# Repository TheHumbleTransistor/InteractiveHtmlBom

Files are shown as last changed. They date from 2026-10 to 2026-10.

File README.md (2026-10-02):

# Interactive HTML BOM plugin for KiCad
## Supports EasyEDA, Eagle, Fusion360 and Allegro PCB designer

icon

This plugin generates a convenient Bill of Materials (BOM) listing with the
ability to visually correlate and easily search for components and their placements
on the PCB. It is particularly useful when hand-soldering a prototype, as it allows
users to quickly find locations of components groups on the board. It is also possible
to reverse lookup the component group by clicking on a footprint on the board drawing.

The plugin utilizes Pcbnew python API to read PCB data and render silkscreen, fab layer,
footprint pads, text, and drawings. BOM table fields and grouping is fully configurable,
additional columns, such as a manufacturer ID, can be added in Schematic editor and
imported either through the netlist file, XML file generated by Eeschema's internal
BOM tool, or from board file itself.

There is an option to include tracks/zones data as well as netlist information allowing
dynamic highlight of nets on the board.

For full description of functionality see [wiki](https://github.com/openscopeproject/InteractiveHtmlBom/wiki).

Generated html page is fully self contained, doesn't need internet connection to work
and can be packaged with documentation of your project or hosted anywhere on the web.

[A demo is worth a thousand words.](https://openscopeproject.org/InteractiveHtmlBomDemo/)

## 3D board view (this fork)

Adds a **3D** button beside F / FB / B. Selecting a BOM row highlights those parts in the 3D
scene and frames the camera on them. When a 3D model is embedded the BOM opens in the 3D view,
unless the browser has saved another choice.

```sh
kicad-cli pcb export glb --include-pads --include-silkscreen --include-soldermask \
    -o board.glb board.kicad_pcb
generate_interactive_bom --glb board.glb board.kicad_pcb
```

Without `--glb` nothing changes: the button is hidden and the output is byte-comparable to
upstream. The `.glb` is embedded, so the result is still one self-contained HTML file.

`--include-silkscreen` is worth the bytes -- reference designators and legends make the 3D view
navigable rather than a field of anonymous grey blocks. Measured on a 170 x 70 mm board:

| glb flags | glb | added to the html |
|---|---|---|
| none | 3.2 MB | 4.3 MB |
| `--include-silkscreen --include-soldermask` | 5.4 MB | 7.2 MB |
| ...`--include-pads` as well (recommended) | 10.6 MB | 14.2 MB |
| ...`--include-tracks` as well | 16.4 MB | 21.9 MB (not worth it) |

three.js adds a further ~2 MB. Pads double the file and are worth it: without them an unplaced
part's land pattern is invisible, which is exactly what an assembler needs to see.

### Z-fighting, and what actually caused it

The artwork layers stipple if you get this wrong. On this board they sit at 1.460 (substrate) /
1.500 (copper) / 1.535 (mask) / 1.545 mm (silk) -- **nothing is coplanar**, the closest pair is
10 um apart. The cause was depth-buffer precision, not coplanarity:

| | near | far | ratio | depth step at the board |
|---|---|---|---|---|
| before | dist/1000 | dist x 10 | 10000 | **17.9 um** -- cannot resolve a 10 um gap |
| after | dist x 0.02 | dist x 4 | 267 | **0.89 um** |

A perspective depth buffer spends most of its precision near the near plane, so an absurd
far/near ratio starves the far end. `setDepthRange()` recomputes it on every frame, because
the camera controls change the viewing distance without going through the fit code. A flat
`polygonOffset` of -1 on artwork faces remains as a cheap guard for boards where faces genuinely
do coincide -- deliberately flat rather than ranked, since large offsets make artwork bleed
through component edges at grazing angles.

### Pin 1

Honours the existing **Highlight first pin** setting (`none` / `all` / `selected`). Each pin-1 pad
gets a 3D marker: a sphere whose bottom sits on top of the part's 3D model, on a cone that runs down
to touch the pad and meets the sphere where their surfaces are tangent. So the marker clears its own
part, with the sphere held between 1.25 mm and 2.5 mm off the board; above that, the 15° outward
lean keeps it off a tall body. A through-hole pin 1 is marked on both faces of the board; on the far
side the sphere clears the leads poking through. A pin-1 marker is plain. A part with no pin 1
(2-4 pads, none named 1, e.g. a diode whose pads are K and A) gets a marker on each pad instead,
with that pad's name printed on the sphere's outer cap, and no pin-1 mark in 2D. The name is fixed
to the marker rather than turning to face the camera; it reads upright with the board's top edge up,
and on bottom-side markers from below. The marker is white at 70 % opacity, with its text opaque.

Every marker's sphere has the same radius, 0.21 mm, so the marker is sized in board millimetres and
grows and shrinks with zoom like the rest of the board. **3D: Pin 1 marker size** in the settings
menu scales it (50–200 %). Markers have their own render pass and light, so the board's dimming
doesn't reach them.

The cone's tip sits on the **board face**, not on the footprint node's origin: the origin is
skewed by any z offset the 3D model carries (`J5`'s is 3.85 mm, which left its mark hovering in
mid-air), and the land pattern is where the mark belongs anyway. It is also drawn for parts the placed
filter is hiding -- an unfitted part is exactly when you need to know which end pin 1 is.

This needs a board-millimetres to model-units mapping, which is the one place the refdes trick
does not reach. It is **solved at load time from every footprint present on both sides**, not
assumed: measured on KiCad 10 the mapping is the identity (board x,y in mm to model x,z in
metres, no offset, no sign flip), and the fit confirms it at a 0.000 mm median residual over 142
footprints. Judge such a fit on the MEDIAN residual, never the worst -- a footprint whose 3D
model carries its own `(offset ...)` is a legitimate outlier, and there were 8 of them. If the
fit fails the markers are disabled with a console warning rather than drawn in the wrong place.

### Silkscreen

The existing **Silkscreen** checkbox governs the 3D view as well as the 2D canvas — no new control;
`silkscreenVisible()` calls into the 3D module the same way `setHighlightPin1()` does.

Silkscreen is identified as the **board-level flat face beyond the mask** on either side, collected
during the pass `tintBoardLayers()` already makes. The board-level part is load-bearing, not
cosmetic: "beyond the front mask" alone means `y > 1.510 mm`, which is *every component on the
board*. Excluding `footprintMeshes` is what makes this the silkscreen rather than the whole
assembly, and the test asserts exactly that — 1154 faces toggle while the component count holds at
7608 in every state.

### The settings menu

All three 3D controls sit together at the end of the view-settings block, between *Offset back
rotation* and *Bom checkboxes*, and each label is prefixed `3D:`.

A **3D view** heading row was tried first and removed: every row in this menu is a bordered box of
the same weight, so a heading reads as just another setting rather than a section title. The prefix
does the grouping work on its own. For the same reason the first 3D row does not get
`menu-label-top` — only the very first row of the whole menu carries a top border, and adding a
divider here would be another visual device of the kind that did not work.

The **Footprint column is hidden by default** (`hiddenColumns` in `initDefaults()`). Default only:
a stored preference wins, the existing `.filter(e => fields.includes(e))` drops it harmlessly on a
BOM with no such column, and the column stays available to re-enable in the column menu.

### Zoom on select

A **3D: Zoom on select** slider in the settings menu. It works like cropping: the percentage is how
much of the board is cropped out of view, centred on the selected parts.

- **0 % (default):** the camera doesn't move; selecting a row only highlights it.
- **10 %** shows about 90 % of the board's area, **50 %** about half, and so on up to **100 %**.
- However high the setting, the camera never gets so close that the selection fills more than 20 %
  of the view, so there is always some board around it for context. It never zooms out past the
  whole board either, so deselecting returns to the whole-board view.

The zoom is absolute, worked out fresh on every selection, so selecting the same row again doesn't
zoom further. The view direction is kept; only the target and distance change. A new value applies
on the next selection.

### Free rotation

The board turns freely in every direction, over the top and underneath, with no stop at the poles:
the view uses three.js's TrackballControls rather than OrbitControls, which keeps a fixed "up"
direction. Left-drag rotates, the wheel zooms and right-drag pans, as before.

### Flip to the selection

Selecting parts that are all on the side facing away from the camera turns the board over, like
turning a page: over half a second the camera rotates half a turn about the line on the board that
looks vertical on screen, keeping its distance. The result is what you'd see after flipping the
board over by hand. If any selected part is on the visible side, the view stays put. The key light
follows the camera to whichever side it is on, so the underside is lit like the top.

### Deselecting

Upstream iBOM has no way to clear a selection: `clearHighlightedFootprints()` is only reachable by
switching BOM mode, and `createRowHighlightHandler()` returns early on the already-selected row.
Tolerable for a highlight tint on the 2D canvas; not for the 3D view, where a selection also dims the
board and holds the camera. This fork adds two ways out:

- **Escape** — works in either mode, hooked into the existing `document.onkeydown` switch.
- **Double-clicking the 3D view** — no raycast; any double-click means "get me out of this",
  whether it lands on a part or on bare board. The camera controls bind no `dblclick` of their own and a
  double-click involves no drag, so the camera is untouched.
- **Clicking the selected row again** — click mode only. In hover mode (the default, when
  *Highlight row only on click* is off) that same handler is bound to `onmousemove` and fires on every
  movement within the row, so toggling there would strobe.

Worth knowing: with the default hover mode the selection follows the mouse across the table and
never clears on its own. Turning on *Highlight row only on click* makes selection deliberate.

### 3D: Board mask

A 0–100 % slider in the settings menu, **75 % by default**. While a row is selected it darkens the board
and every unselected component, leaving the green highlighted parts bright — useful on a dense board,
and especially at 0 % auto-zoom where the camera no longer flies to the selection.

**Implemented by turning the lights down, not by recolouring materials.** The highlight is emissive,
and emissive is added independently of scene lighting, so scaling `scene.environmentIntensity` and
the key light darkens everything *except* the selection. Two lines, against cloning and restoring
~36 materials across 7608 meshes. Measured inside the 3D pane:

| slider | `environmentIntensity` | board (non-highlight) | highlight, mean R |
|---|---|---|---|
| 0 % | 0.62 | 92.3 | 174.1 |
| 50 % | 0.341 | 74.9 | 200.6 |
| 100 % | 0.062 | **34.7** | **214.5** |

`DIM_FLOOR` is the light scale at 100 %; the slider lerps between 1 and it.

The selected part's *diffuse* darkens along with everything else, so its emissive is raised while
dimming (`HIGHLIGHT_EMISSIVE_DIM`) or it reads as a muddy dark part with a red tinge rather than a
clean red one. `DIM_FACTOR` controls how far down everything else goes.

Only active while something is selected — deselecting restores the lights, verified. Pin-1 markers are
drawn in their own pass with their own lighting, so they stay bright on the dimmed board;
deliberate, they are a marker rather than scenery.

### Only show placed parts

A **3D: only show placed parts** checkbox in the settings menu, on by default. With it on, the 3D view shows
only the parts ticked in the BOM's *Placed* column -- so the board fills in as you assemble it,
and at a glance you see what the half-built board in front of you should look like.

**DNP parts are hidden in 3D until they are ticked Placed**, whether or not this is on.
Selecting one reveals it with a red highlight instead of the usual green. A DNP part that has
been ticked Placed is shown tinted red. A
part counts as DNP if `--dnp-field` marks it or KiCad's own DNP flag (`kicad_dnp`) is set.

**Land patterns stay visible, and selecting an unplaced row reveals that part** — fully opaque,
exactly as a placed part looks — so you can see the shape of the thing you are about to fit.

It was briefly revealed as a *translucent* ghost instead, which rendered as a see-through tangle of
red edges. The culprit was the `depthWrite = false` that the transparency required: it also stops
the part's own faces occluding **each other**, so every back face and interior surface showed
through the front. No opacity value fixes that — the geometry is self-overlapping and unsorted.
Opaque is both correct and less code.

Nothing is overlaid on the components themselves -- no tint, no shading, no transparency -- so a
populated board renders as it really looks and the green highlight is the only thing distinguishing
a selection. Verified by material inspection: of 7608 component meshes, 0 are transparent, 0
share a tinted material and 0 carry a polygon offset. Both matter for the actual workflow: you need to see where a part goes,
and what it looks like, *before* you can fit it and tick it off.

**Pads and silkscreen are board-level, not children of the footprint node** -- so hiding a part
is simply `node.visible = false` and the land pattern stays put. Counted on this board:

| plane (mm) | under footprints | board-level | what |
|---|---|---|---|
| 1.545 | **371** | 0 | component bottom faces |
| 1.535 | 0 | 1153 | silkscreen |
| 1.510 | 0 | 1 | top soldermask, one full-board mesh |
| 1.500 | 0 | 582 | top copper |
| 1.460 | 0 | 500 | substrate, top face |
| 0.000 | 0 | 84 | substrate, bottom face |
| −0.040 | 0 | 166 | bottom copper |
| −0.050 | 0 | 1 | bottom soldermask, one full-board mesh |

Earlier versions tried to split each footprint into "artwork" and "body" by height, on the belief
that pads were inside it. They are not, and every height rule tried caught component geometry
instead -- a +/-0.2 mm window took TSSOP leads at 1.58-1.70 mm, and "a plane shared by most
footprints" took the 1.545 mm bottom faces, which is true of every SMD's underside. Hiding a part
left a flat cross-section of it welded to the board. **Measure which meshes are actually inside
the node before designing a rule around it.**

### DNP parts

DNP parts are marked so an assembler can't miss them. Every badge below explains itself on hover,
and clicking it shows the same text, which also works on touchscreens:

- **BOM:** DNP refs are red and struck through, and a row that is entirely DNP is tinted red with lightened text and a red stripe that stays when the row is
  selected.
- **2D and 3D:** a red cross over each DNP footprint, shown while the **DNP markers** setting is
  on (the default). A selected DNP part is highlighted red in both views instead of green. In 3D
  the cross sits on the bare land pattern, and the part is tinted red once it is ticked Placed.
- **Checkbox progress** (e.g. *Placed 0/140*) leaves DNP parts out of the total.
- **Grouping** always puts DNP parts in their own row, whatever `--group-fields` says.
- **Ticking Placed** (or whichever column `--mark-when-checked` names) on a DNP row asks for
  confirmation first. The operator can still go ahead.
- Hovering a red, struck-through reference explains it ("DNP = Do Not Populate").
- KiCad's DNP column (`kicad_dnp`) is headed **DNP** and shows a red **DNP** badge on DNP rows. It
  is hidden by default (the column menu brings it back), and left out entirely on a board with no
  DNP parts in the BOM.

A part counts as DNP if `--dnp-field` marks it or KiCad's DNP flag (`kicad_dnp`) is set. A part
whose *value* says "DNP" (as a word, any case) is treated as DNP too, and its value cell gets a
yellow **WARNING** badge: DNP belongs in KiCad's DNP property, not the value.

### Lighting

**Every component material KiCad exports is `metalness: 1`** -- all 7608 meshes on this board.
A fully metallic surface has no diffuse response, so with only lights and nothing to reflect it
can only render dark: a connector housing whose material is pure white measured RGB ~120, i.e.
grey. Raising light intensities does not help, because a metal barely responds to a light at all.

The fix is image-based lighting -- `RoomEnvironment` through `PMREMGenerator`, giving those metals
a full hemisphere to reflect -- plus one soft directional light so shapes still read. A white part
now renders ~210 from any angle.

**Tone mapping is not cosmetic here.** Without it, values above 1.0 clip and a white part becomes a
flat 255 across its whole face, losing all shape. `NeutralToneMapping` (Khronos PBR Neutral) rolls
highlights off while holding colours where they are; it exists for product visualisation, which is
exactly this job. ACES works too but shifts hue. Measured on the same white part: **0.06 % of
pixels clipped**, against a blown-out face before.

`ENV_INTENSITY`, `KEY_INTENSITY` and `TONE_EXPOSURE` are at the top of `ibom3d.js`. Note that
changing them changes the *board* too -- `MASK_COLOR` and `COPPER_COLOR` were both retuned darker
once IBL raised the overall exposure.

### Layer colours

KiCad **does** honour the stackup for silkscreen -- this board declares white silk and the GLB
carries `#f5f5f5` -- but gives copper a flat `#808080`, which is nobody's idea of copper. Both
soldermask and copper are therefore tinted, and the mask is made slightly translucent so the
copper beneath reads through. A green board is what reads as "a PCB" on screen whatever the real
stackup says; set `MASK_COLOR = null` to keep the exported colour instead. `MASK_COLOR`,
`MASK_OPACITY`, `COPPER_COLOR`, `COPPER_METALNESS` and `COPPER_ROUGHNESS` are at the top of
`ibom3d.js`.

Copper also needs its **PBR properties** overridden, not just its colour. KiCad exports it as
`metalness 1 / roughness 0.4`, and a fully metallic surface has no diffuse term -- with no
environment map to reflect, it is black except where a light happens to catch it. Measured over
the copper-toned pixels of an isolated render:

| | copper pixels | mean RGB |
|---|---|---|
| metalness 1, top-down | 5367 | (140, 121, 82) |
| metalness 1, shallow | **0 -- none** | copper vanishes |
| metalness 0, top-down | 5730 | (225, 197, 138) |
| metalness 0, shallow | 4050 | (221, 192, 134) |

At `metalness 0 / roughness 0.7` the colour is within ~2 % across viewing angles.

Identify the layers by **area**, not mesh count or height rank: the full-board planes on a side are
the substrate face and the mask, and copper is the busiest plane between them. Ranking from the top
puts the tint on the silkscreen, and a "more than 20 meshes" filter discards the soldermask
outright, it being a single mesh. For the same reason `findBoardFaces()` cannot look for a
substrate *solid*: the board is flat faces too.

**Both faces are tinted**, by `identifySide()` run once per side. The rule generalises with one
substitution: the mask is the **outermost** full-board plane on its side — highest at the front,
lowest at the back — with the substrate the inner one. The back was skipped for a while
(`tintBoardLayers()` opened with `if (y < mid) return`), which left the bottom mask and copper in
KiCad's greys and reading as absent:

| plane | before | after |
|---|---|---|
| −0.050 bottom mask | `#373737` grey | `#185230` green, α 0.80 |
| −0.040 bottom copper | `#bababa` grey, **metalness 1** | `#c3903e` gold, metalness 0 |

Note the bottom copper arrived at `metalness 1`, so it had the black-at-grazing-angles problem too;
routing it through the same tint pass fixes that as well.

It rides iBOM's own `CHECKBOX_CHANGE_EVENT`, so no checkbox bookkeeping is patched. It follows
whichever column `--mark-when-checked` names, defaulting to `Placed`.

**How the mapping works.** KiCad's GLB export names every scene node for its reference
designator, so a BOM row finds its geometry by name -- no coordinate transform, no lookup table
to keep in sync, and it survives the board moving underneath it. Parts with no 3D model are
skipped and counted in a corner note. On this project's board 142 of 178 footprints have named
nodes, and the 36 that do not are exactly the `TP*`/`MH*`/`FID*`/logo set that iBOM already
excludes from the BOM -- so no BOM row is ever unmatched.

**Design notes**, mostly so they are not re-litigated:

- three.js r169 is vendored **unmodified** under `web/three/` (MIT, `LICENSE` included) and
  inlined as `data:` URIs in an import map. ES modules cannot be concatenated and three.js has
  shipped no UMD build since r160, so something must resolve the bare `three` specifier inside
  an inlined `<script type=module>`. A `data:` import map does it **with no bundler**, which
  keeps the single-file property and adds no Node toolchain.
- The one build-time edit: `GLTFLoader` imports `BufferGeometryUtils` by *relative* path, and a
  relative specifier cannot resolve when the importing module is itself a `data:` URI. That
  single import is rewritten to a bare specifier in `core/ibom.py`; the vendored file on disk
  stays pristine.
- KiCad exports GLB in **metres**, not millimetres.
- `tests/check_3d.py` screenshots a generated file in headless Chromium (software WebGL, no GPU
  needed). It is the only thing that can catch a blank 3D pane, which is otherwise silent.

### Demo board

`demo/` holds a small KiCad 10 board for trying changes without another project. R4 and C5 are DNP
through KiCad's DNP property, and R7 only through its value ("DNP"), which shows the WARNING badge.
R6 and C6 are on the back. D1's pads are named K and A rather than numbered, which shows how a part
with no pin 1 is labelled. Every part has a Manufacturer and MPN. Its 3D models are copied into
`demo/3dmodels/`, so it builds without KiCad's model library.

```sh
demo/build.sh                 # -> demo/out/ibom-demo.html
```

It needs `kicad-cli` and a python that can `import pcbnew` (`$PYTHON`, default `/usr/bin/python3`).
CI runs the same script for every pull request and for pushes to `master`, and keeps the result as
the `ibom-demo.html` artifact (unzipped) for 30 days. On a pull request, each build
posts a new comment linking its demo; a newer push cancels a build still in progress, so only the
latest commit gets one. Pushing a `v*` tag also attaches the demo to that tag's release as
`ibom-demo-<tag>.html`, creating the release if there isn't one.

### Mounting type

A **Mounting Type** column, visible by default, shows **SMT** (grey rounded rectangle, a pad) or
**TH** (grey ring, an annular ring). Sort on it to group the two, or type `smt` / `th` in the
filter box. Hovering the header or a value explains the acronym.

The value comes from KiCad's footprint type (Footprint Properties, *SMD* or *Through hole*). A
footprint left *Unspecified*, or a board from another EDA tool, counts as TH if any of its pads is
through-hole and SMT otherwise.

### Default columns

Without `--show-fields` the BOM shows **Manufacturer** and **MPN** columns alongside Value and
Footprint, even on a board where no part sets them. Grouping still defaults to Value and Footprint.

### Side, and sorting by more than one column

A **Side** column, visible by default, shows **Top** or **Bottom**. While it is shown, a group with
parts on both sides is split into a top row and a bottom row; hide the column and they merge back.

**Shift+click** a column header to add it as a further sort key, e.g. Side then Mounting Type. A
small number on each sorted header shows its priority. A plain click sorts by that column alone.

### Polarized parts and pin 1

Each part is classified **Yes**, **No** or **Unknown** for whether its orientation matters. The
classification is shown in a **Polarized** column, hidden by default (the column menu shows it).

- **No** requires evidence from the part's schematic symbol and none to the contrary: a two-pad
  R, C, L, FB or F whose Description (copied from the symbol) reads "Resistor", "Unpolarized
  capacitor", "Inductor", "Ferrite bead", "Fuse" or mentions ceramic, or whose symbol footprint
  filters are `R_*`, `C_*`, `L_*` and the like, **and** whose footprint silkscreen is symmetric
  about both of its axes (a "+", cathode band or pin-1 dot breaks that). The footprint alone never
  makes a part No, since polarized capacitors are often placed on plain, symmetric `C_` footprints.
- **Yes**: a polarity signal (`CP_` footprint or filter, "Polarized capacitor", a diode or LED), or
  more than two pins.
- **Unknown**: everything else, including conflicting evidence (a bidirectional TVS diode, an
  inductor whose footprint marks pin 1), no silkscreen, or no symbol fields at all.

**Omit pin-1 marker on bidirectional parts**, on by default, hides the pin-1 marks of parts classified No,
in both the 2D and 3D views. Turn it off to mark every part again. Yes and Unknown parts always keep
their marks.

### Sound Effect on Placed

Off by default. With it on, ticking a line's Placed box plays a clay block being set down for each
of its parts, stepping up in pitch as the stack grows, up to 10. Lines ticked during a run, or
within half a second after it, add to the same run. Placing the last part plays a short fanfare.
Unticking is silent. The sound is synthesised in the browser, so the BOM carries no audio files.

## Installation and Usage

See [project wiki](https://github.com/openscopeproject/InteractiveHtmlBom/wiki/Installation) for instructions.

## License and credits

Plugin code is licensed under MIT license, see `LICENSE` for more info.

Html page uses [Split.js](https://github.com/nathancahill/Split.js),
[PEP.js](https://github.com/jquery/PEP) and (stripped down)
[lz-string.js](https://github.com/pieroxy/lz-string) libraries that get embedded into
generated bom page.

`units.py` is borrowed from [KiBom](https://github.com/SchrodingersGat/KiBoM)
plugin (MIT license).

`svgpath.py` is heavily based on
[svgpathtools](https://github.com/mathandy/svgpathtools) module (MIT license).

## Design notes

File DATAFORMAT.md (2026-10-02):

# pcbdata struct

This document describes pcbdata json structure that plugin
extracts from PCB file and injects into generated bom page.

Notes on conventions:
* Coordinate system has origin in top left corner i.e. Y grows downwards
* All angles are in degrees measured clockwise from positive X axis vector
* Units are arbitrary but some browsers will not handle too large numbers
  well so sticking to mm/mils is preferred.

```js
pcbdata = {
   // Describes bounding box of all edge cut drawings.
   // Used for determining default zoom and pan values to fit
   // whole board on canvas.
  "edges_bbox": {
    "minx": 1,
    "miny": 2,
    "maxx": 100,
    "maxy": 200,
  },
  // Describes all edge cut drawings including ones in footprints.
  // See drawing structure description below.
  "edges": [drawing1, drawing2, ...],
  "drawings": {
    // Contains all drawings + reference + value texts on silkscreen
    // layer grouped by front and back.
    "silkscreen": {
      "F": [drawing1, drawing2, ...],
      "B": [drawing1, drawing2, ...],
    },
    // Same as above but for fabrication layer.
    "fabrication": {
      "F": [drawing1, drawing2, ...],
      "B": [drawing1, drawing2, ...],
    },
  },
  // Describes footprints.
  // See footprint structure description below.
  // index of entry corresponds to component's numeric ID
  "footprints": [
    footprint1,
    footprint2,
    ...
  ],
  // Optional track data. Vias are 0 length tracks.
  "tracks": {
    "F": [
      {
        // In case of line segment or via (via is 0 length segment)
        "start": [x, y],
        "end": [x, y],
        // In case of arc
        "center": [x, y],
        "startangle":
        "radius": radius,
        "startangle": angle1,
        "endangle": angle2,
        // Common fields
        "width": w,
        // Optional net name
        "net": netname,
        // Optional drill diameter (un-tented vias only)
        "drillsize": x
      },
      ...
    ],
    "B": [...]
  },
  // Optional zone data (should be present if tracks are present).
  "zones": {
    "F": [
      {
        // SVG path of the polygon given as 'd' attribute of svg spec.
        // If "svgpath" is present "polygons" is ignored.
        "svgpath": svgpath,
        // optional fillrule flag, defaults to nonzero
        "fillrule": "nonzero" | "evenodd",
        "polygons": [
          // Set of polylines same as in polygon drawing.
          [[point1x, point1y], [point2x, point2y], ...],
        ],
        // Optional net name.
        "net": netname,
      },
      ...
    ],
    "B": [...]
  },
  // Optional net name list.
  "nets": [net1, net2, ...],
  // PCB metadata from the title block.
  "metadata": {
    "title": "title",
    "revision": "rev",
    "company": "Horns and Hoofs",
    "date": "2019-04-18",
    "variant": "var" // optional
  },
  // Contains full bom table as well as filtered by front/back.
  // See bom row description below.
  "bom": {
    "both": [bomrow1, bomrow2, ...],
    "F":  [bomrow1, bomrow2, ...],
    "B":  [bomrow1, bomrow2, ...],
    // numeric IDs of DNP components that are not in BOM
    "skipped": [id1, id2, ...],
    // numeric IDs of all DNP components, whether or not they are in BOM
    "dnp": [id1, id2, ...],
    // numeric IDs of components that are DNP only because their value says
    // "DNP" (a subset of "dnp")
    "dnp_value": [id1, id2, ...],
    // Fields map is keyed on component ID with values being field data.
    // It's order corresponds to order of fields data in config struct.
    "fields" {
      id1: [field1, field2, ...],
      id2: [field1, field2, ...],
      ...
    }
  },
  // Contains parsed stroke data from newstroke font for
  // characters used on the pcb.
  "font_data": {
    "a": {
      "w": character_width,
      // Contains array of polylines that form the character shape.
      "l": [
        [[point1x, point1y], [point2x, point2y],...],
        ...
      ]
    },
    "%": {
      ...
    },
    ...
  },
}
```

# drawing struct

All drawings are either graphical items (arcs, lines, circles, curves)
or text.

Rendering method and properties are determined based on `type`
attribute.

## graphical items

### segment

```js
{
  "type": "segment",
  "start": [x, y],
  "end": [x, y],
  "width": width,
}
```

### rect

```js
{
  "type": "rect",
  "start": [x, y], // coordinates of opposing corners
  "end": [x, y],
  "width": width,
}
```

### circle

```js
{
  "type": "circle",
  "start": [x, y],
  "radius": radius,
  // Optional boolean, defaults to 0
  "filled": 0,
  // Line width (only has effect for non-filled shapes)
  "width": width,
}
```

### arc

```js
{
  "type": "arc",
  "width": width,
  // SVG path of the arc given as 'd' attribute of svg spec.
  // If this parameter is specified everything below it is ignored.
  "svgpath": svgpath,
  "start": [x, y], // arc center
  "radius": radius,
  "startangle": angle1,
  "endangle": angle2,
}
```

### curve

```js
{
  "type": "curve", // Bezier curve
  "start": [x, y],
  "end": [x, y],
  "cpa": [x, y], // control point A
  "cpb": [x, y], // control point B
  "width": width,
}
```

### polygon

```js
{
  "type": "polygon",
  // Optional, defaults to 1
  "filled": 1,
  // Line width (only has effect for non-filled shapes)
  "width": width
  // SVG path of the polygon given as 'd' attribute of svg spec.
  // If this parameter is specified everything below it is ignored.
  "svgpath": svgpath,
  "pos": [x, y],
  "angle": angle,
  "polygons": [
    // Polygons are described as set of outlines.
    [
      [point1x, point1y], [point2x, point2y], ...
    ],
    ...
  ]
}
```

## text

```js
{
  "pos": [x, y],
  "text": text,
  // SVG path of the text given as 'd' attribute of svg spec.
  // If this parameter is specified then height, width, angle,
  // text attributes and justification is ignored. Rendering engine
  // will not attempt to read character data from newstroke font and
  // will draw the path as is. "thickness" will be used as stroke width.
  "svgpath": svgpath,
  // If polygons are specified then remaining attributes are ignored
  "polygons": [
    // Polygons are described as set of outlines.
    [
      [point1x, point1y], [point2x, point2y], ...
    ],
    ...
  ],
  "height": height,
  "width": width,
  // -1: justify left/top
  // 0: justify center
  // 1: justify right/bot
  "justify": [horizontal, vertical],
  // Either the thickness or the fillrule must be used
  "thickness": thickness,
  // fillrule is only supported for svgpath
  "fillrule": "nonzero" | "evenodd",
  "attr": [
    // may include none, one or both
    "italic", "mirrored"
  ],
  "angle": angle,
  // Present only if text is reference designator
  "ref": 1,
  // Present only if text is component value
  "val": 1,
}
```

# footprint struct

Footprints are a collection of pads, drawings and some metadata.

```js
{
  "ref": reference,
  // Optional. "yes", "no" or "unknown": whether the part's orientation
  // matters. "no" only with evidence from the schematic symbol (KiCad).
  "polarized": polarized,
  // Optional. "smd" or "th" from the ECAD footprint type; if absent, the
  // footprint counts as "th" when any of its pads is through-hole.
  "mount": mount,
  "center": [x, y],
  "bbox": {
    // Position of the rotation center of the bounding box.
    "pos": [x, y],
    // Rotation angle in degrees.
    "angle": angle,
    // Left top corner position relative to center (after rotation)
    "relpos": [x, y],
    "size": [x, y],
  },
  "pads": [
    {
      "layers": [
        // Contains one or both
        "F", "B",
      ],
      "pos": [x, y],
      "size": [x, y],
      "angle": angle,
      // Only present if pad is considered first pin.
      // Pins are considered first if it's name is one of
      // 1, A, A1, P1, PAD1
      // OR footprint has no pads named as one of above and
      // current pad's name is lexicographically smallest.
      "pin1": 1,
      // Only present when the footprint has no first pin as above and 2-4
      // named pads (e.g. a diode's K and A); then every pad carries its
      // name and none is marked "pin1".
      "name": name,
      // Shape is one of "rect", "oval", "circle", "roundrect", "chamfrect", custom".
      "shape": shape,
      // Only present if shape is "custom".
      // SVG path of the polygon given as 'd' attribute of svg spec.
      // If "svgpath" is present "polygons", "pos", "angle" are ignored.
      "svgpath": svgpath,
      "polygons": [
        // Set of polylines same as in polygon drawing.
        [[point1x, point1y], [point2x, point2y], ...],
        ...
      ],
      // Only present if shape is "roundrect" or "chamfrect".
      "radius": radius,
      // Only present if shape is "chamfrect".
      // chamfpos is a bitmask, left = 1, right = 2, bottom left = 4, bottom right = 8
      "chamfpos": chamfpos,
      "chamfratio": ratio,
      // Pad type is "th" for standard and NPTH pads
      // "smd" otherwise.
      "type": type,
      // Present only if type is "th".
      // One of "circle", "oblong" or "rect".
      "drillshape": drillshape,
      // Present only if type is "th". In case of circle shape x is diameter, y is ignored.
      "drillsize": [x, y],
      // Optional attribute.
      "offset": [x, y],
      // Optional net name
      "net": netname,
    },
    ...
  ],
  "drawings": [
    // Contains only copper F_Cu, B_Cu drawings of the footprint.
    {
      // One of "F", "B".
      "layer": layer,
      // See drawing struct description above.
      "drawing": drawing,
    },
    ...
  ],
  // One of "F", "B".
  "layer": layer,
}
```

# bom row struct

Bom row is a list of reference sets

Reference set is array of tuples of (ref, id) where id is just
a unique numeric identifier for each footprint that helps avoid
collisions when references are duplicated.

```js
[
  [reference_name, footprint_id],
  ...
]
```

# config struct

```js
config = {
  "dark_mode": bool,
  "show_pads": bool,
  "show_fabrication": bool,
  "show_silkscreen": bool,
  "highlight_pin1": "none" | "all" | "selected",
  "redraw_on_drag": bool,
  "board_rotation": int,
  "checkboxes": "checkbox1,checkbox2,...",
  "bom_view": "bom-only" | "left-right" | "top-bottom",
  "layer_view": "F" | "FB" | "B",
  "extra_fields": ["field1_name", "field2_name", ...],
}
```

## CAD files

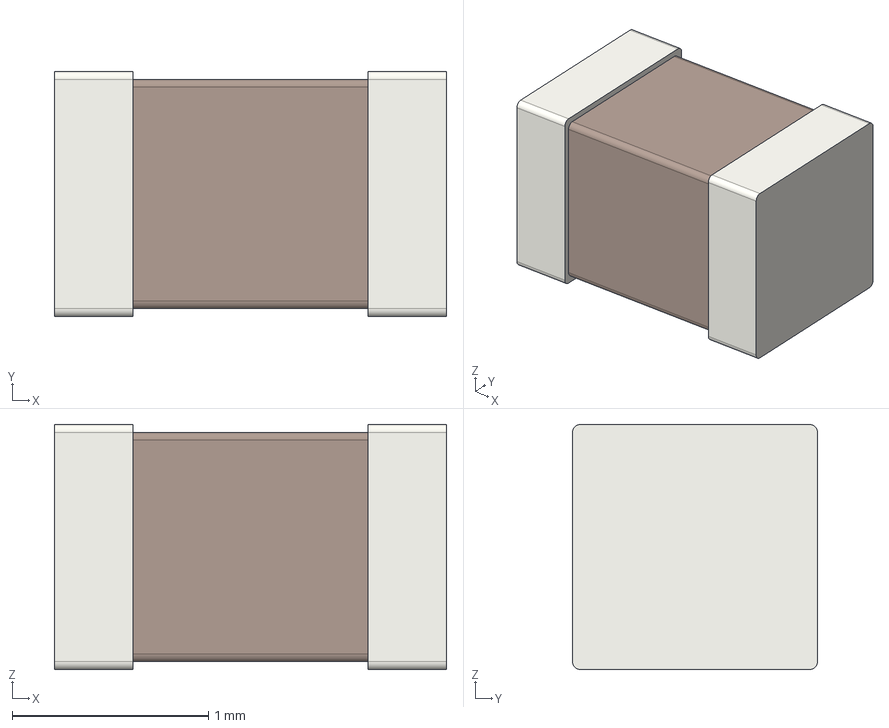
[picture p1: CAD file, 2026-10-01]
demo/3dmodels/C_0805_2012Metric.step
2.00 x 1.25 x 1.25 mm

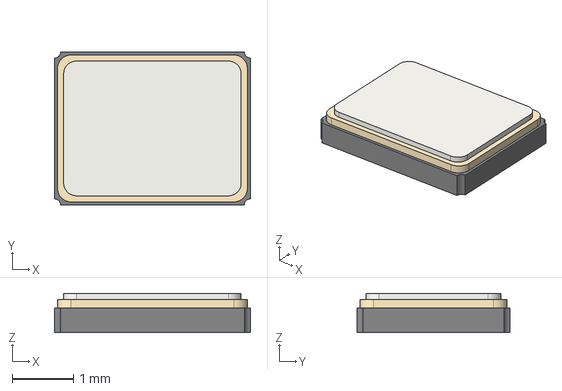
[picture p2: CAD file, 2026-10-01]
demo/3dmodels/Crystal_SMD_3225-4Pin_3.2x2.5mm.step
3.20 x 2.50 x 0.64 mm

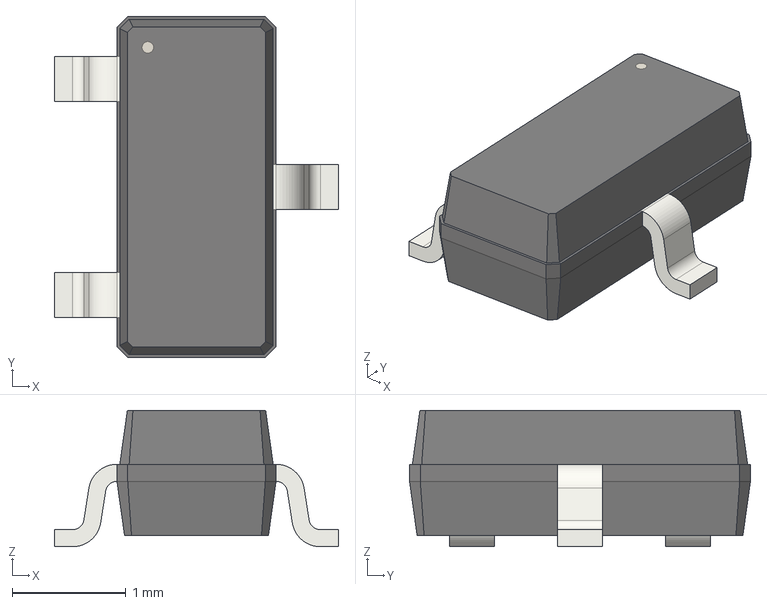
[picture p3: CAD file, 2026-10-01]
demo/3dmodels/SOT-23.step
2.50 x 3.00 x 1.20 mm

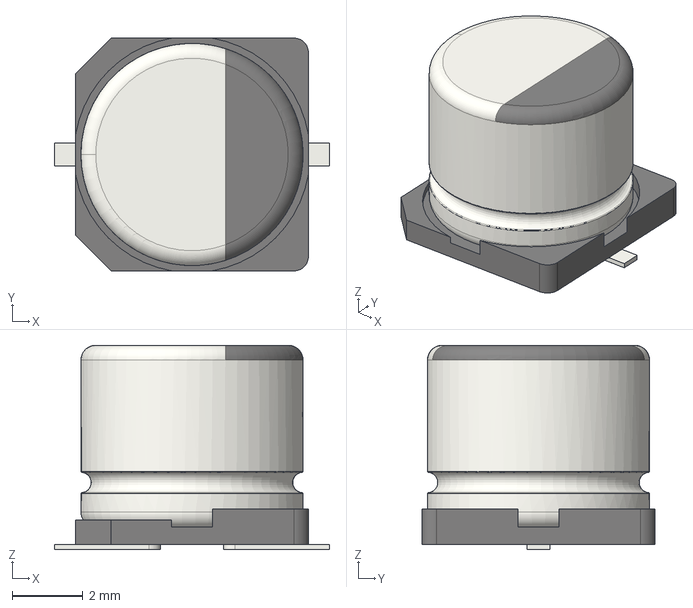
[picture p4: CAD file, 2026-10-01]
demo/3dmodels/CP_Elec_6.3x5.8.step
7.80 x 6.60 x 5.80 mm

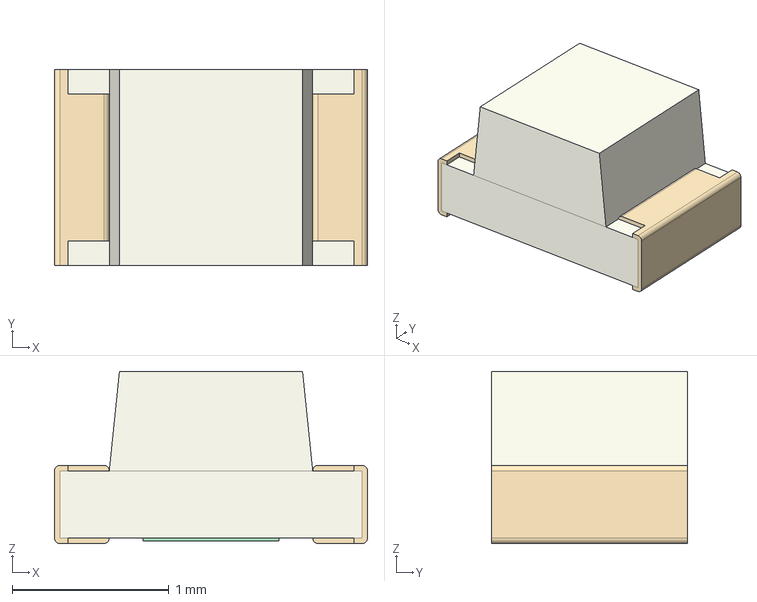
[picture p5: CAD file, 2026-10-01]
demo/3dmodels/LED_0805_2012Metric.step
2.00 x 1.25 x 1.10 mm

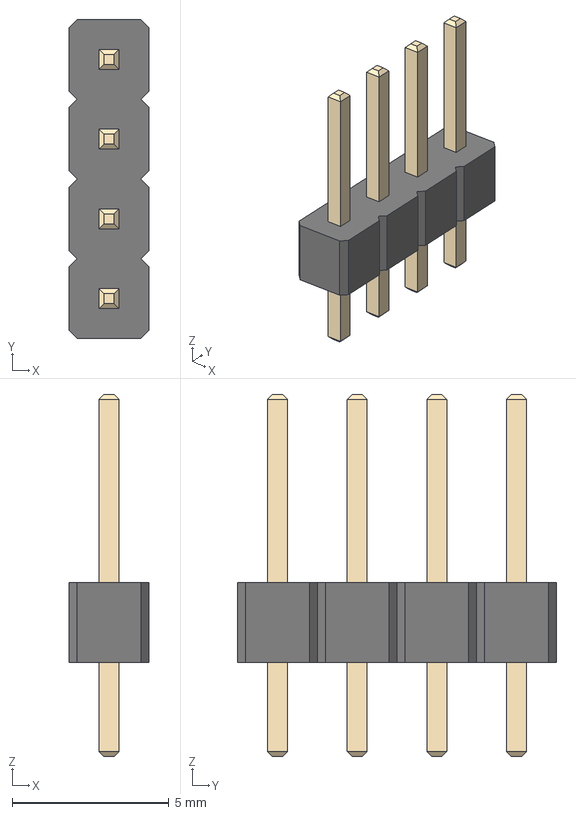
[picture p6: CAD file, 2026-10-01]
demo/3dmodels/PinHeader_1x04_P2.54mm_Vertical.step
2.54 x 10.2 x 11.5 mm

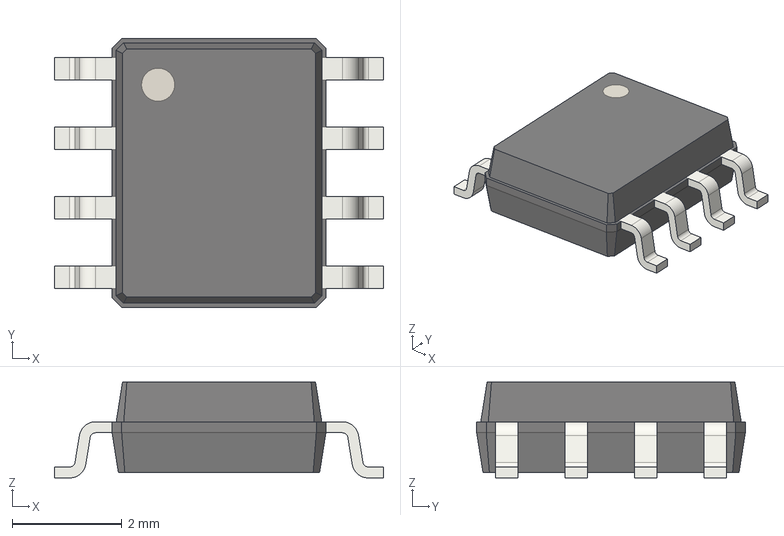
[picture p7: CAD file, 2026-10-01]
demo/3dmodels/SOIC-8_3.9x4.9mm_P1.27mm.step
6.00 x 4.90 x 1.75 mm

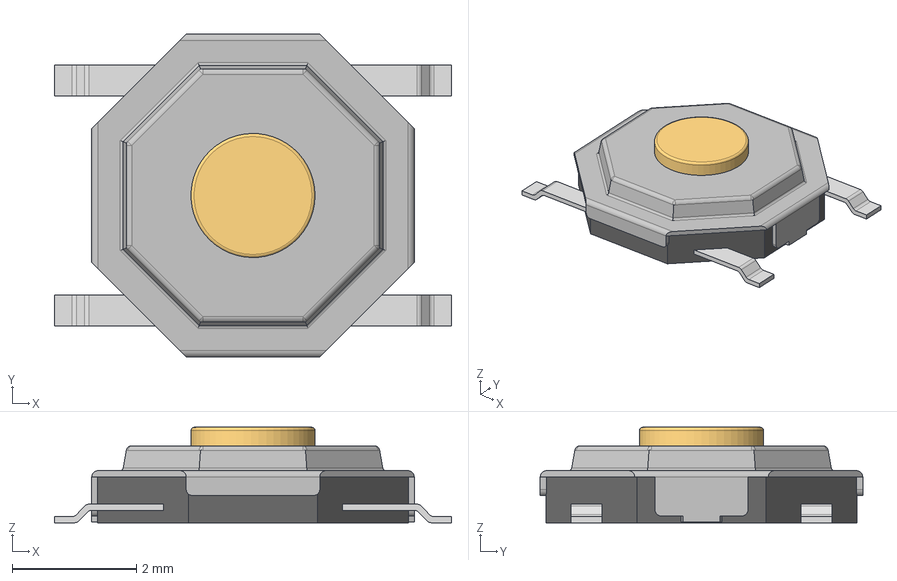
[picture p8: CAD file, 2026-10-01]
demo/3dmodels/SW_SPST_TL3342.step
6.40 x 5.20 x 1.54 mm

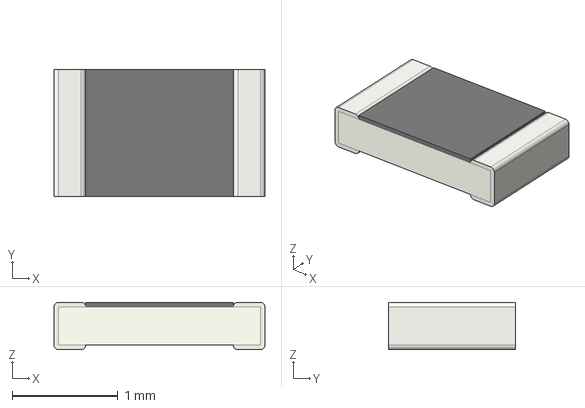
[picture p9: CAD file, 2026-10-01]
demo/3dmodels/R_0805_2012Metric.step
2.00 x 1.20 x 0.45 mm

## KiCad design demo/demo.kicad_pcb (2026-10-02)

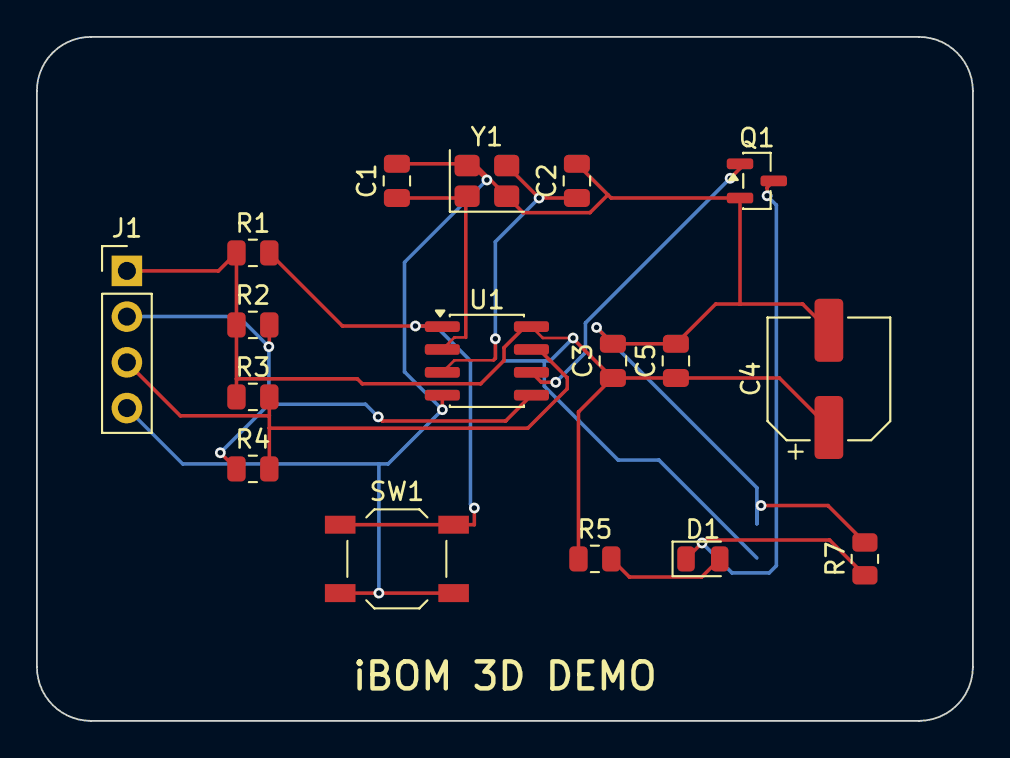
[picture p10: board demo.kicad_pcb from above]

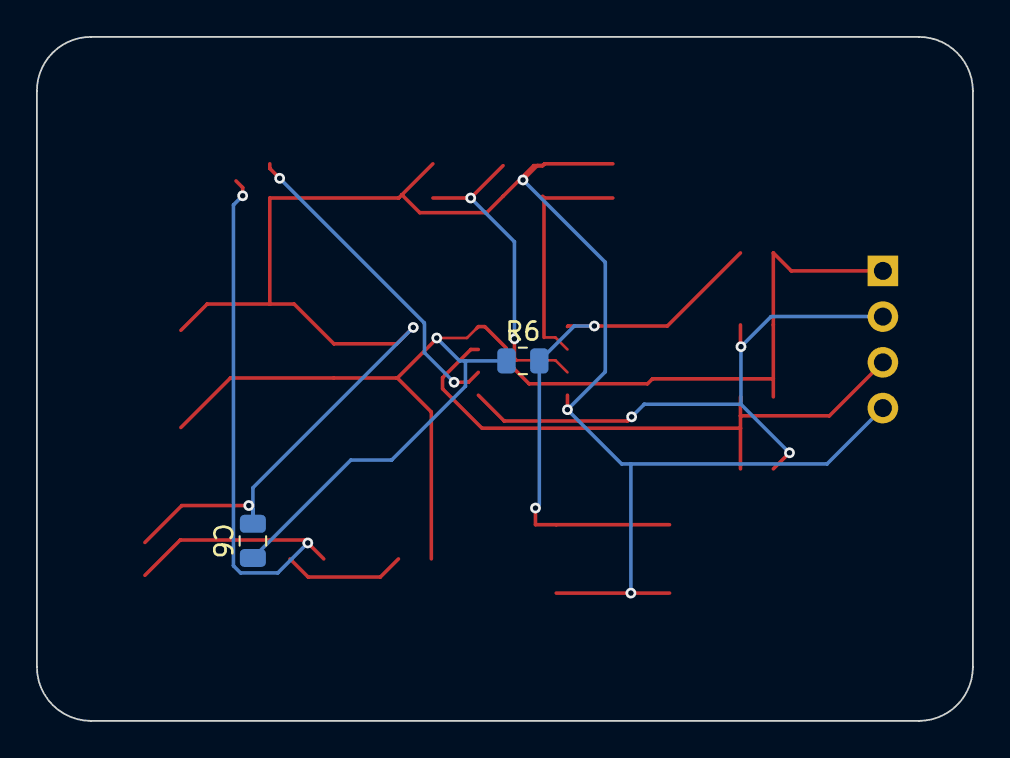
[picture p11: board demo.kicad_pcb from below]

Board: 2 copper layers, 52.0 x 38.0 mm, 19 parts (2 on the bottom side), 10 nets.

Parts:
C1, C2: 22pF; C_0805_2012Metric
C3, C6: 100nF; C_0805_2012Metric
C4: 47uF; CP_Elec_6.3x5.8
C5: 1uF; C_0805_2012Metric
D1: Green; LED_0805_2012Metric
J1: Conn_01x04; PinHeader_1x04_P2.54mm_Vertical
Q1: BSS138; SOT-23
R1, R6: 10k; R_0805_2012Metric
R2, R3: 4.7k; R_0805_2012Metric
R4: 0R; R_0805_2012Metric
R5: 1k; R_0805_2012Metric
R7: DNP; R_0805_2012Metric
SW1: Reset; SW_SPST_TL3342
U1: ATtiny85; SOIC-8_3.9x4.9mm_P1.27mm
Y1: 16MHz; Crystal_SMD_3225-4Pin_3.2x2.5mm

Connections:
GND: C1.2, C2.2, C3.2, C4.2, C5.2, C6.2, J1.4, Q1.2, R7.2, SW1.2, U1.4, Y1.2, Y1.4
LED: Q1.1, U1.6
LED_A: D1.A, R5.2
LED_K: D1.K, Q1.3, R7.1
RST: R1.2, R6.2, SW1.1, U1.1
SCL: J1.3, R3.2, R4.2, U1.7
SDA: J1.2, R2.2, R4.1, U1.5
VCC: C3.1, C4.1, C5.1, C6.1, J1.1, R1.1, R2.1, R3.1, R5.1, R6.1, U1.8
XTAL1: C1.1, U1.2, Y1.1
XTAL2: C2.1, U1.3, Y1.3

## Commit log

2026-08-21 3D board view, driven by KiCad's GLB export
    Adds a 3D button beside F / FB / B. Selecting a BOM row highlights those
    parts in the 3D scene and frames the camera on them.
    kicad-cli pcb export glb -o board.glb board.kicad_pcb
    generate_interactive_bom --glb board.glb board.kicad_pcb
    Without --glb nothing changes: the button is hidden and output matches
    upstream. Verified against a real 178-footprint board.
    WHY THIS IS NOW CHEAP. Issue #225 (2021) stalled on vrm360/VRML, which was
    reported unusable beyond small boards, and the only implementation was a
    prerendered background image. KiCad has since gained native GLB export, and
    its nodes are NAMED FOR THEIR REFERENCE DESIGNATOR -- so a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
2026-08-21 3D view: pads, real z-fighting fix, and ghosting for unplaced parts
    PADS. `--include-pads` is now part of the recommended export. Doubles the glb
    (5.4 -> 10.6 MB) and is worth it: without pads an unplaced part's land pattern
    is invisible, which is precisely what an assembler needs to see.
    Z-FIGHTING -- and the cause was NOT coplanarity. Measured, the layers sit at
    1.460 (substrate) / 1.500 (copper) / 1.535 (mask) / 1.545 mm (silk). Nothing is
    coplanar; the closest pair is 10 um apart. The problem was depth-buffer
    precision:
    before near=dist/1000 far=dist*10 ratio 10000 -> 17.9 um per step
    after near=dist*0.02 far=dist*4 ratio 267 -> 0.89 um per step
    A perspective de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
2026-08-21 3D view: fix flattened component remnants, and tint the board layers
    Two regressions from the previous commit, both reported from the bench.
    FLATTENED COMPONENTS. Hiding an unplaced part left flat fragments of it on the
    board. The artwork/body split used "flat face within 0.2 mm of a board face",
    and a TSSOP's gull-wing leads sit at 1.58-1.70 mm -- inside that window. So the
    leads were classed as artwork, exempted from hiding, and every part left a
    flattened ghost behind.
    Two further rules were tried and measured before one worked:
    - "a plane shared by >=25% of footprints is a board layer" caught 1.995 mm,
    which is simply the top face of ~60 identical 0805s;
    - "the median footprin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
2026-08-21 3D view: hide the whole footprint node; keep the mask's real colour
    FLATTENED COMPONENTS, take two. Hiding an unplaced part still left a flat
    cross-section of it on the board -- correctly diagnosed from the bench as "the
    cross section of where it meets the board". Measured, it was 371 meshes at
    1.545 mm across 139 footprints: component BOTTOM FACES.
    The root error was an assumption I never checked. Pads are NOT children of the
    footprint node:
    plane (mm) under footprints board-level what
    1.545 371 0 component bottom faces
    1.535 0 1153 silkscreen
    1.510 0 1 soldermask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
2026-08-21 3D view: raise the ghost opacity; confirm components carry no overlay
    GHOST more opaque, as asked: GHOST_OPACITY 0.32 -> 0.6 and GHOST_EMISSIVE
    0.22 -> 0.45. Clearly red now while still reading as "not yet fitted" -- the
    board and its pads remain visible through it. The two values are next to each
    other at the top of the module; the previous pass had over-corrected after the
    ghost was mistaken for a rendering fault.
    NO MASK COLOUR OR SHADING ON COMPONENTS, checked rather than asserted. Tinting
    only ever touches the two board planes the area analysis identifies, so parts
    render exactly as KiCad exported them. Measured across 7608 component meshes:
    transparent 0
    sh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
2026-08-21 3D view: pin-1 dots follow the 2D palette, and sit on the board
    COLOUR now comes from the 2D view's own `--pin1-outline-color` CSS variable
    (#ffb629 light / #ffa800 dark) rather than a hardcoded blue, so the dot matches
    the canvas and tracks dark mode for free -- render.js reads the same property.
    setDarkMode() refreshes the dots, since the variable changes under them.
    Two bugs surfaced while verifying it, both of which made the dots useless in the
    case they matter most:
    - They were positioned at the footprint NODE ORIGIN plus the dot radius. That
    origin is skewed by any z offset the 3D model carries, so J5 -- whose model
    sits 3.85 mm up -- had its dot hovering at 5.95 mm in mid-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
2026-08-21 3D view: image-based lighting, so white components render white
    Bench report: "populated component models are masked/shaded -- white components
    are appearing as grey."
    Nothing is overlaid on the components; that was checked, not assumed (0 of 7608
    meshes transparent, tinted or offset). The cause is that KiCad exports EVERY
    component material with metalness 1 -- all 7608 of them. A fully metallic
    surface has no diffuse term, so with only lights and no environment to reflect
    it can only render dark. J5's housing, whose material is literally 1,1,1 white,
    measured RGB ~120.
    That also rules out the obvious fix: raising light intensities would have done
    almost nothing, because a metal barely res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
2026-08-21 3D view: slider for how much to auto-zoom when a BOM row is selected
    Selecting a row always jumped the camera to a fit-on-the-selection, which is
    right for inspecting a part and wrong when working across the board. Now a
    0-100% slider in the settings menu, styled like Board rotation.
    0% (the default) the camera does not move at all; the row is only highlighted
    100% the previous behaviour, bit-for-bit
    The fraction is RELATIVE to where the camera already is:
    target = lerp(currentTarget, selectionCentre, pct/100)
    dist = lerp(currentDist, todaysFitDist, pct/100)
    which is what lets 0% mean "do not move" rather than "frame the whole board".
    The accepted trade, r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
2026-08-21 3D view: setting to dim the board while a row is selected
    Darkens the board and every unselected component while a BOM row is selected,
    leaving the red highlighted parts bright. Off by default. Useful on a dense
    board, and especially at the new 0% auto-zoom default where the camera no longer
    flies to the selection.
    IMPLEMENTED BY TURNING THE LIGHTS DOWN, not by recolouring materials. The
    highlight is emissive and emissive is added independently of scene lighting, so
    scaling scene.environmentIntensity and the key light darkens everything EXCEPT
    the selection. Two lines, against cloning and restoring ~36 materials across
    7608 meshes. Measured inside the 3D pane, selecting the U5/U6/U7/U9 row: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
2026-08-22 Add a way to deselect; rename the dim slider to "3D: Board mask"
    DESELECT. Reported from the bench: "How do you deselect? I'm unable to do
    that." Correct -- upstream iBOM has no way to clear a selection at all.
    clearHighlightedFootprints() is only reachable by switching BOM mode, and
    createRowHighlightHandler() returns early on the already-selected row. That is
    tolerable when a selection is just a red tint on the 2D canvas, and not once it
    also dims the board and holds the camera.
    Two additive ways out, neither of which changes existing behaviour:
    - Escape, hooked into the existing document.onkeydown switch rather than a
    competing listener. Works in both modes; ignored while a text f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
2026-08-22 Deselect on double-click in the 3D view; board mask defaults to 75%
    DOUBLE-CLICK the 3D view to clear the selection, joining Escape and
    click-the-selected-row-again. Six lines and no raycast: any double-click means
    "get me out of this", whether it lands on a part or on bare board.
    OrbitControls binds no dblclick of its own and a double-click involves no drag,
    so nothing conflicts -- verified the camera position and target are byte-equal
    across the gesture.
    Measured with the mask at 80%: selecting takes refs to 4 and
    environmentIntensity 0.62 -> 0.1736; a double-click on the canvas returns them
    to 0 and 0.62.
    BOARD MASK now defaults to 75% rather than 0. On a fresh profile that reads
    env 0.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
2026-08-22 3D view: a selected part is always opaque
    Reported from the bench: a selected but unplaced part looked buggy -- "nearly
    see-through with some red edges of the model" -- and looked fine once marked
    placed.
    The cause was the `depthWrite = false` that the ghost's transparency required.
    It does not only let the board show through the part; it stops the part's own
    faces occluding EACH OTHER, so every back face and interior surface rendered
    through the front. That is a tangle of red edges, not a translucent solid, and
    no opacity value fixes it -- the geometry is self-overlapping and unsorted.
    So a selected part is now opaque whether placed or not. The reveal branch keeps
    only the one thing it st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
2026-08-22 Settings menu: drop the "3D view" heading, prefix the labels instead
    The heading added in 7894f72 did not read as a group. Every row in this menu is
    a bordered box of the same weight, so a heading row looks like just another
    setting rather than a section title.
    Reverted to the simpler thing: the three controls stay adjacent, between Offset
    back rotation and Bom checkboxes, and each label carries a "3D:" prefix that
    does the grouping work on its own.
    Zoom on select -> 3D: Zoom on select
    Board mask -> 3D: Board mask
    Only show placed parts -> 3D: Only show placed parts
    The first 3D row deliberately does NOT get menu-label-top. Only the very first
    row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
2026-10-01 3D view: never show DNP parts
    With "3D: Only show placed parts" off, every footprint was shown, DNP
    included. DNP parts are now hidden regardless of that setting, and
    selecting one does not reveal it; the note under the view says how many
    selected parts are DNP instead.
    DNP can't be read off bom.skipped: that only holds DNP parts when
    --dnp-field is set, and it also holds blacklisted and virtual parts. A
    common setup (KiCad's DNP flag, shown as a kicad_dnp column) leaves DNP
    parts in the BOM, so pcbdata.bom gains a "dnp" list covering both
    --dnp-field and kicad_dnp.
    Verified on the pump controller board: R41/R51 (kicad_dnp) hidden with
    the filter off and on; 140 other parts visible with it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
2026-10-01 Default "Highlight first pin" to "selected"
    Changes the generation-time default (CLI, settings dialog, ini) and the
    page's fallback from "none" to "selected". A bare --highlight-pin1 still
    means "all", and an explicit value still wins.
    Fixes #3
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2026-10-01 Make DNP parts unmistakable in the BOM, 2D and 3D views
    With KiCad's DNP flag, a DNP part was an ordinary BOM row whose only
    marker was "DNP" in a text column, and it looked like any other part
    on both boards.
    - BOM: DNP refs red and struck through, a red DNP badge in the
    References cell, and all-DNP rows tinted red with a red left stripe
    that survives row selection.
    - 2D canvas: red cross over each DNP footprint's bounding box, drawn
    always; "DNP outlined" now covers kicad_dnp parts too.
    - 3D: red cross on the bare land pattern of each (hidden) DNP part.
    - Checkbox progress excludes DNP parts from the total and the count.
    Fixes #1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
2026-10-01 DNP: own BOM group, confirm before marking placed, plainer labels
    From review on #1:
    - DNP parts always get their own BOM row, whether or not --group-fields
    includes the DNP field, so a DNP part can't hide in a populated group.
    - Ticking the placed checkbox (--mark-when-checked, default "Placed") on
    a DNP row asks for confirmation first. Cancelling leaves it unticked;
    the operator can still go ahead.
    - kicad_dnp is headed "Do Not Populate" in the BOM and column menu, and
    its value is "Do Not Populate" instead of "DNP".
    - All-DNP rows also get lightened text.
    Also fixes CSV/TSV export, which only read text from MARK/A elements and
    would have written "null" for the new DNP ref spans;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
2026-10-01 Add a "DNP markers" setting for the red DNP crosses
    The red cross over DNP footprints in 2D and 3D was always on. A new
    "DNP markers" checkbox (default on, persisted like the others) now
    controls it in both views. Upstream's "DNP outlined" is unchanged; the
    BOM-side DNP styling and the red tint on a placed DNP part stay on.
    Fixes #12
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2026-10-01 BOM: add a Mounting Type column (SMT / TH)
    Assembly runs as an SMT pass followed by a through-hole pass, so a
    Mounting Type column, visible by default and sortable, shows SMT or TH
    for each row, with tooltips on the header and values. The filter box
    matches it too.
    The KiCad parser records the footprint type attribute (SMD / Through
    hole) as footprint "mount". When it is absent (footprint type left
    Unspecified, or another EDA tool), a footprint counts as TH if any pad
    is through-hole.
    Fixes #17
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2026-10-01 Mounting Type: SMT icon is a wider rectangle with tighter corners
    9 x 6.5 instead of 8 x 8, corner radius 1.8 -> 1.0.
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2026-10-01 BOM: leave out the DNP column when no BOM row is DNP
    On a board with no DNP parts in the BOM the DNP column is always empty,
    so it is dropped from the available columns: no header, no cells, no
    column-menu entry. DNP parts excluded from the BOM by --dnp-field don't
    count, since they have no row to badge.
    Fixes #18
2026-10-01 Demo board: DRC-clean placement, autorouted, rounded corners
    The first board failed DRC: a courtyard overlap, two shorts, two
    solder-mask bridges and seven silkscreen violations. Parts are now
    spread out and the outline has 3 mm corner radii.
    Routed with Freerouting 2.4.1 (all 39 connections, 128 segments, 16
    vias). It necks a few segments down to 0.15 mm between pads, so the
    board's minimum track width is 0.15 mm. kicad-cli pcb drc
    --severity-all now reports 0 violations and 0 unconnected items.
    build.sh also exports tracks into the GLB, so the routing shows in 3D.
    [demo.kicad_pcb]
2026-10-01 Treat parts whose value says "DNP" as DNP, with a WARNING badge
    A value naming the part DNP ("DNP" as a whole word, any case:
    "DNP", "dnp", "10k DNP", "DNP_10k") now marks the part DNP: its own BOM
    row, the DNP badge, red markers, hidden in 3D and the Placed
    confirmation. Its value cell also gets a yellow WARNING badge whose
    tooltip says DNP belongs in KiCad's DNP property, not the value.
    pcbdata.bom gains "dnp_value" for the badge. The DNP column now badges
    any part in the DNP list rather than reading kicad_dnp's text, so it
    covers these parts too. CSV/TSV export leaves the WARNING text out of
    the value.
    Fixes #20
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2026-10-01 3D view: keep the DNP crosses red when zoomed out
    The board artwork, soldermask included, is drawn with a -1 polygon
    offset (biasArtwork). From a distance that bias exceeded the 0.05 mm
    lift of the DNP crosses, so the translucent dark-green mask was drawn
    over them and they read as black until you zoomed in. The crosses now
    carry a -4 offset so they always win against the mask beneath them.
    Measured on the demo board, sampling the centre of each on-screen cross
    bar: at 300 mm 0/36 red pixels before, 32/36 after (bars are ~1 px
    wide there); at 150 mm 0/36 before, 36/36 after; unchanged when close.
    Fixes #34
2026-10-01 BOM: tooltip on DNP references; hide the DNP column by default
    Hovering a red, struck-through DNP reference now shows the same
    "DNP = Do Not Populate" explanation as the DNP badge, so the styling
    explains itself without the DNP column. That column joins Footprint in
    the default hidden columns; a stored choice still wins and the column
    menu brings it back.
    Fixes #39
2026-10-01 Demo board: Manufacturer/MPN on every part; R7 is DNP only by value
    Every part now carries real Manufacturer and MPN fields (hidden, on the
    Fab layer, so nothing lands on the silkscreen).
    R7 ("10k DNP", 0805, LED_K to GND) is DNP only through its value, so the
    demo shows the WARNING badge from #29 next to the two parts that use
    KiCad's DNP property (R4, C5).
    R7 routed with Freerouting; kicad-cli pcb drc --severity-all reports 0
    violations and 0 unconnected items.
    Fixes #28
    [demo.kicad_pcb]
2026-10-01 BOM: Side column, split groups by side, and multi-column sort
    A Side column (Top / Bottom), visible by default. While it is shown, a
    group with parts on both sides is split into a top row and a bottom
    row, client-side, so hiding the column merges them back without
    regenerating the BOM. The filter box matches it too.
    Shift+click on a column header adds it as a further sort key (a plain
    click still sorts by that column alone), so the BOM can be sorted by
    Side and Mounting Type together. Each sorted header shows its priority.
    Sort state is now kept by column name, so the marks survive the header
    being rebuilt.
    Fixes #36
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2026-10-01 Remove upstream's PyPI release workflow
    This fork isn't published to PyPI, and on every v* tag the workflow
    would try to publish upstream's InteractiveHtmlBom package and fail.
    Releases are handled by the Demo workflow, which attaches the demo
    iBOM to the tag's release.
2026-10-01 Version 3.0.0: the fork's own version line
    The fork no longer tracks upstream releases, so it gets its own
    version. 3.0.0 sits above upstream's 2.x on purpose: the package keeps
    upstream's name, and a lower number would let `pip install --upgrade
    InteractiveHtmlBom` replace the fork with upstream from PyPI. Unlike
    the old v2.11.2-3d.N tags, it's a valid package version, so the wheel
    and the HTML footer now report it.
2026-10-01 3D view: flip to the other side when the selection is out of view
    Selecting parts that are all on the side facing away from the camera
    now mirrors the camera through the board's plane, so the view shows
    that side at the same distance and heading. Nothing else about the
    user's view changes, and it applies whether or not zoom-on-select is
    on. If any selected part is on the visible side, the view stays put.
    The key light now follows the camera to whichever side it is on; fixed
    above the board, it left the underside at about half the brightness
    (demo board, centre of view: 35.6 -> 43.3 mean, top 65.3).
    Fixes #47
2026-10-01 3D view: animate the flip over half a second
    The flip now swings the camera over the board's edge in 500 ms with an
    ease-in-out curve, instead of jumping. Only the elevation moves;
    distance, heading and target are held, and it lands exactly where the
    instant flip did. A new selection or a mouse drag stops it where it is.
2026-10-01 3D view: turn the board over like a page instead of end over end
    The flip now rotates the camera half a turn about the board line that
    looks vertical on screen (the camera's up direction laid onto the
    board), rather than swinging it over the far edge. The board turns
    over sideways, as it would in your hands, and ends up seen from above
    in screen terms with its left and right swapped. Camera up rotates with
    it, so OrbitControls' cached up-axis quaternion is refreshed whenever
    up changes.
2026-10-01 3D view: pin-1 map-pin markers instead of spheres
    Each pin-1 pad now gets a map-pin marker: an upside-down teardrop with
    a "1" on it, its tip on the pad, in the pin-1 colour. It's a sprite, so
    it always faces the camera, at a constant ~40 px on screen.
    It is drawn without depth testing, so the part body (which usually
    covers pin 1) can't hide it, and shown only while its side of the board
    faces the camera, so the board can't either and far-side markers don't
    show through. After a flip the markers stay upright on screen.
    Fixes #50
2026-10-01 CI: run the tests on KiCad 10 too
    - Add KiCad 10.0 to the Test matrix, and move actions/checkout to v7
    (Node 20 deprecation).
    - KiCad 10's image ships a Debian typing_extensions that pip can't
    upgrade in place, so hatch is installed with --ignore-installed.
    - Importing the package outside KiCad registers its action plugin,
    which trips a KiCad 10 assertion (PgmOrNull) that aborts under pytest.
    The tests now import in CLI mode, which skips registration exactly as
    the generate_interactive_bom entry point does, and add a test that
    imports the KiCad parser so pcbnew is still exercised on every version.
    - The repo-root __init__.py (KiCad's plugin entry) imported `plugin`
    by name, whi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
2026-10-01 Pin-1 marker: 3D sphere on a cone, with size and opacity settings
    The marker is now a 3D shape standing straight up off the pad: a cone
    whose tip touches the pad with a sphere on top, in the pin-1 colour,
    lit by a light that follows the camera. A "1" sprite on the sphere
    always faces the camera. It keeps a constant on-screen size.
    Markers are drawn in a second render pass after the scene, with the
    depth buffer cleared between, so part bodies can't hide them while the
    marker still shades and occludes itself correctly. Board-side
    visibility is unchanged.
    New settings, saved like the others and hidden without a 3D view:
    "3D: Pin 1 marker size" (25-300 %, default 100) and "3D: Pin 1 marker
    opa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
2026-10-01 Pin-1 marker: sized from the pad, seated on the part, tangent cone
    From review on #52:
    - The sphere's bottom sits on top of the part's 3D model (its bounds on
    the board face it is mounted to), so tall parts no longer cover it;
    a cone runs from the pad up to meet the sphere where their surfaces
    are tangent. Without a model, or for a part lower than the radius,
    the sphere sits one radius above the pad.
    - Sized in board millimetres: radius is half the pin-1 pad's longer
    side (min 0.4 mm), so it zooms with the board. "3D: Pin 1 marker
    size" is now a scale factor on that.
    - Opacity setting removed; markers are always opaque.
    - The "1" label is gone.
    - Markers still get their own rende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
2026-10-01 3D view: rotate freely, with no stop at the poles
    OrbitControls keeps a fixed up direction, so it can't carry the camera
    past straight overhead or straight underneath. The view now uses
    three.js r169's TrackballControls (vendored unmodified, like the rest of
    web/three/), which has no fixed up and turns the board freely in every
    direction. Left-drag rotates, wheel zooms, right-drag pans, as before;
    staticMoving keeps the stop-on-release behaviour.
    TrackballControls only moves the camera in update(), so update() is
    pumped once per frame while a gesture is live, plus one frame after it
    ends so a wheel step lands; the page still runs no animation loop at
    rest. handleResize() is called when the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
2026-10-01 Open in the 3D view when the BOM has a 3D model
    With a GLB embedded and no saved view choice, the BOM now opens in the
    3D view instead of --layer-view's F / FB / B. A saved choice still
    wins, and a BOM without a 3D model is unchanged.
    Fixes #55
2026-10-01 Pin-1 marker: size from the pad's shorter side
    Per review: the radius now follows the pin-1 pad's shorter side, and
    100 % matches what the previous formula gave at 50 %: 0.35 x the
    shorter side (min 0.2 mm). On 0805 pads that's 0.35 mm, the same as
    before at 50 %; narrow pads come out smaller and square pads larger.
2026-10-01 Pin-1 marker: point 25 % in from the pad's outer end
    Per review, the cone's tip no longer lands on the pad centre but 25 % of
    the pad's length in from its end facing away from the part body.
    "Away" is the direction from the centroid of the footprint's pads to
    the pin-1 pad, snapped to whichever of the pad's own axes it best
    matches, so a corner pin (SOIC pin 1) is marked at its toe rather than
    pushed sideways along the row. Single-pad footprints keep the centre.
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

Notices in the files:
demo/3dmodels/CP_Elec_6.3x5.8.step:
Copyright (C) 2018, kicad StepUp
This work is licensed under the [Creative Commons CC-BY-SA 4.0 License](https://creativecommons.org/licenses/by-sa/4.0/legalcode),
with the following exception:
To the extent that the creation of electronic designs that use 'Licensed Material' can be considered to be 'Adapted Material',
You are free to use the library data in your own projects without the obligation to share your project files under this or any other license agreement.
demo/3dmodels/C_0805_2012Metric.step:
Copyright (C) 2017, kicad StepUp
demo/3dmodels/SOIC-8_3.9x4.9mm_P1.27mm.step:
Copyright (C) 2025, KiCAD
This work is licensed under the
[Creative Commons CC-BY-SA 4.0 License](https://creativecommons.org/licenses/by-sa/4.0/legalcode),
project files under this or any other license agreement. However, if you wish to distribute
